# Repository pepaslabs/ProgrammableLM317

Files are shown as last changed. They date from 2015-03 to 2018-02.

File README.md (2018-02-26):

# ProgrammableLM317

A TTL-serial programmable LM317 voltage voltage supply circuit board design.

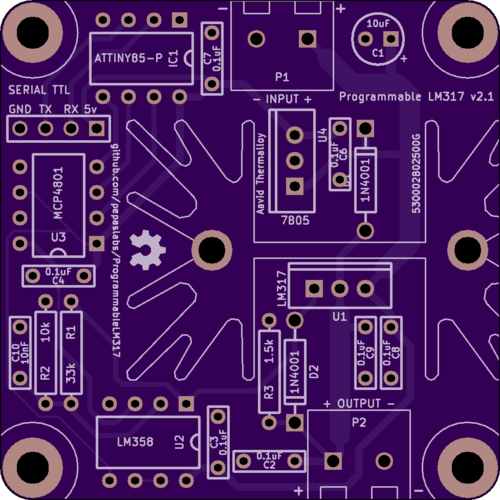
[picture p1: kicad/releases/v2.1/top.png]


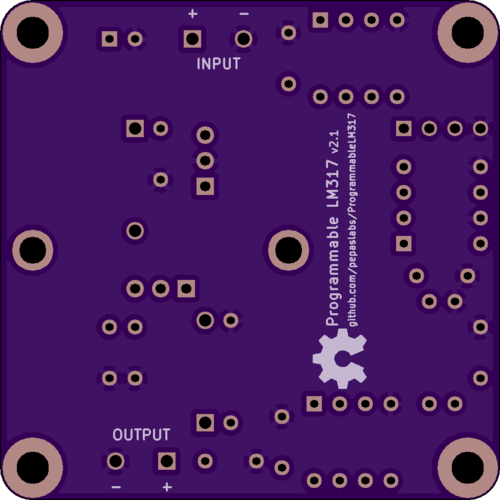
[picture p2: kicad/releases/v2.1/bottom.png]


Schematic: [pdf](kicad/releases/v2.1/ProgrammableLM317.pdf).

Gerbers: [zip](kicad/releases/v2.1/gerbers.zip)

OSHPark: [link](https://oshpark.com/shared_projects/kM7WPtAO)

## License

This board design is [Open-Source Hardware](http://www.oshwa.org/definition/).  It is licensed under the [MIT License](http://opensource.org/licenses/MIT).  It was designed by Jason Pepas.

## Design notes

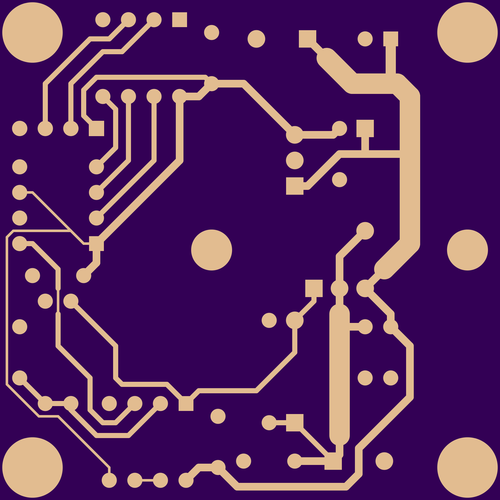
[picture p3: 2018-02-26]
kicad/releases/v2.1/top-copper.png

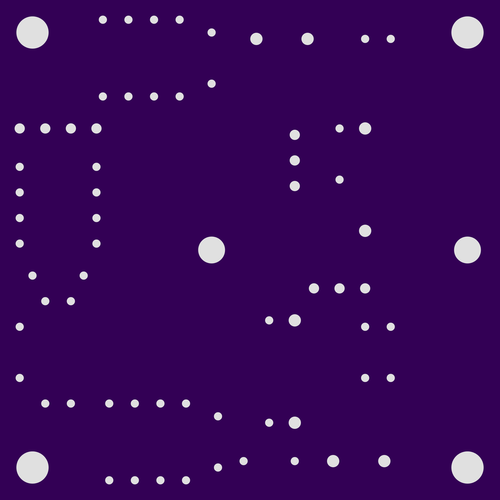
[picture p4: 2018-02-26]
kicad/releases/v2.1/drills.png

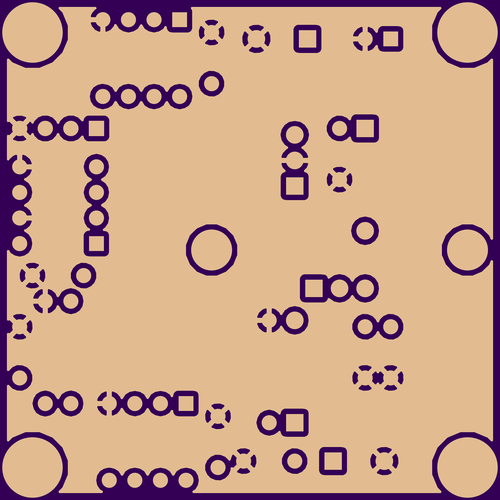
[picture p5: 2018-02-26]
kicad/releases/v2.1/bottom-copper.png

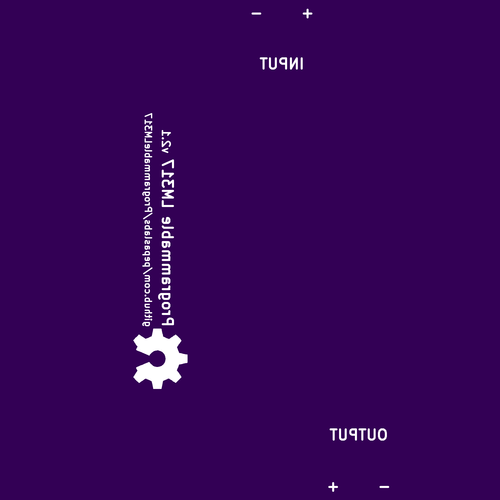
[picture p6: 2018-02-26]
kicad/releases/v2.1/bottom-silk.png

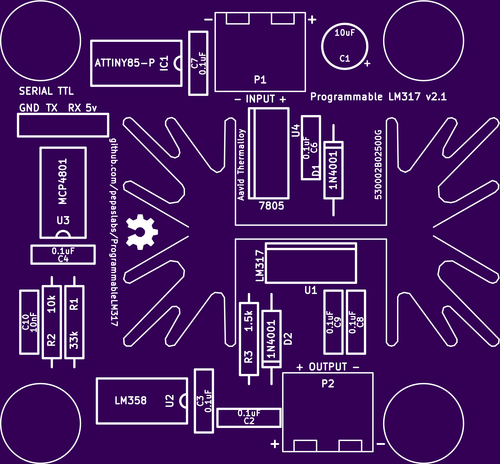
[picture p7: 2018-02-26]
kicad/releases/v2.1/top-silk.png

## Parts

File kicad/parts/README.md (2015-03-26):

KiCADParts
==========

A collection of KiCAD schematic symbols and component footprints which I have created / tweaked / used.

## Design Constraints / Preferred Values / Conventions

* Label size X / size Y / thickness ratio: 1 / 1 / 0.2
 * Preferred component value label size X / size Y / thickness: 0.03" / 0.03" / 0.006"
 * Minimum component value label size X / size Y / thickness: 0.025" / 0.025" / 0.005"
* Outline thickness: 0.01"

## Pads

* Ratios:
 * **_A_**: Size X: 1, Size Y: 1, Offset Y: 0
 * **_B_**: Size X: 1, Size Y: 1.5, Offset Y: 0.25
 * **_C_**: Size X: 1, Size Y: 2, Offset Y: 0

### 0.060" nominal pads

0.059 pads

Pads sized just under 0.060" (allows routing a 0.020" trace without violating DRC).

 * **_059A_**: Size X: 0.059", Size Y: 0.059", Offset Y: 0
 * **_059B_**: Size X: 0.059", Size Y: 0.0885", Offset Y: 0.01475"
 * **_059C_**: Size X: 0.059", Size Y: 0.118", Offset Y: 0

Drill size is 0.032" (the KiCAD default), which is used for:
 * 1/4W resistors
 * small signal diodes
 * ceramic and small electrolytic capacitors
 * DIP leads
 * TO-92 leads

### 0.070" nominal pads

0.069 pads

Pads sized just under 0.070" (allows routing a 0.010" trace without violating DRC).

 * **_069A_**: Size X: 0.069", Size Y: 0.069", Offset Y: 0
 * **_069B_**: Size X: 0.069", Size Y: 0.1035", Offset Y: 0.01725"
 * **_069C_**: Size X: 0.069", Size Y: 0.138", Offset Y: 0

Drill size is 0.040", which is used for:
 * 1/2W resistors
 * TO-220 leads

### 0.080" nominal pads

0.079 pads

Pads sized just under 0.080" (does not allow routing traces).

 * **_079A_**: Size X: 0.079", Size Y: 0.079", Offset Y: 0
 * **_079B_**: Size X: 0.079", Size Y: 0.1185", Offset Y: 0.01975"
 * **_079C_**: Size X: 0.079", Size Y: 0.158", Offset Y: 0

Drill size is 0.056", which is used for:
 * TO-218 leads
 * TO-247 leads

## Footprints

resistors_PL.mod

DIP_PL.mod

transistors_PL.mod

TO-220_PL.mod

## License

Parts which I have created are released under the [MIT License](http://opensource.org/licenses/MIT).  Parts which I have modified are subject to their original license.

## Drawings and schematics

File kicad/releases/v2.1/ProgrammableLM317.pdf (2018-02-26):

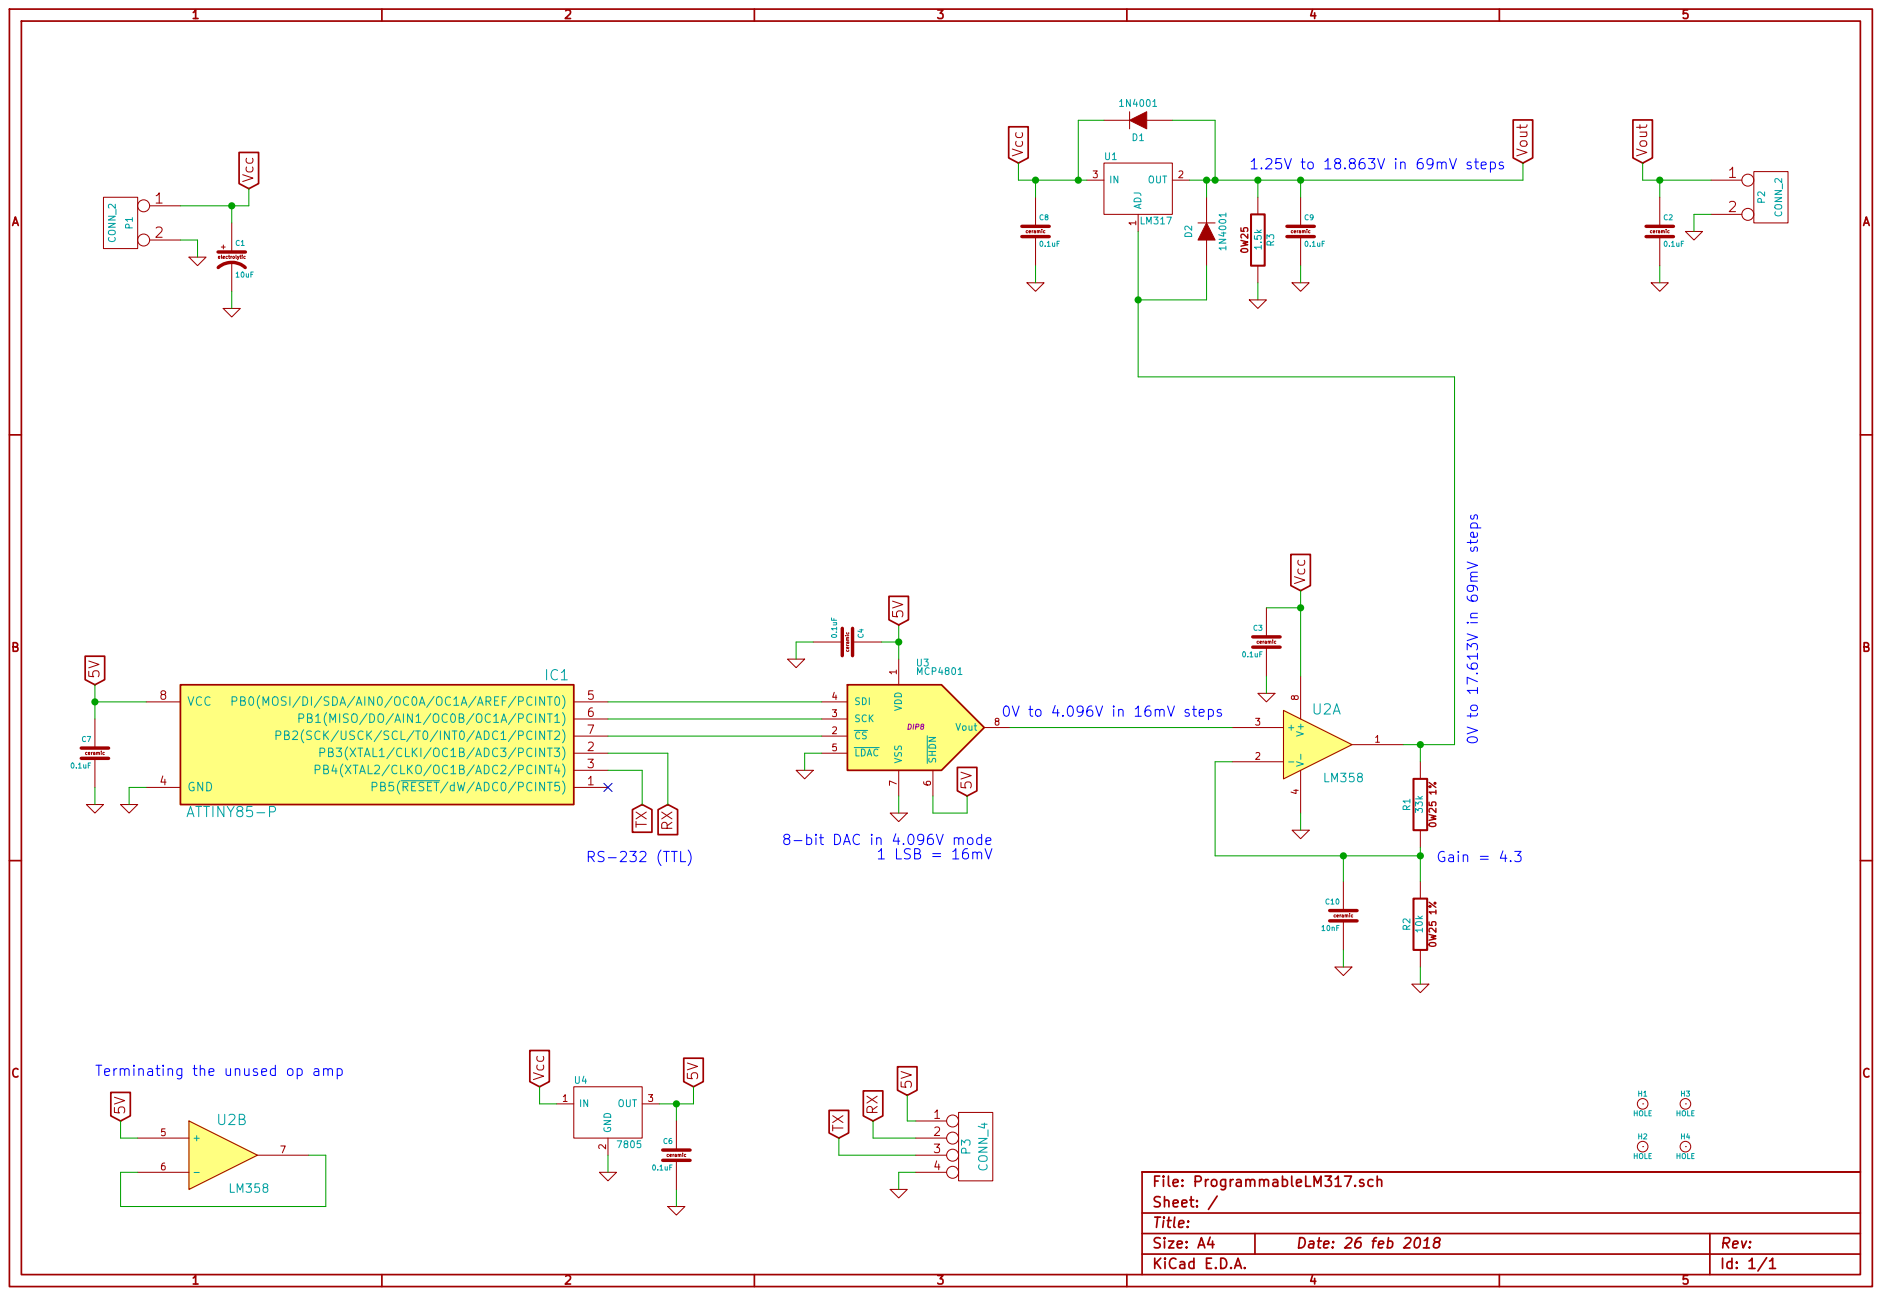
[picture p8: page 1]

8-bit DAC in 4.096V mode

Terminating the unused op amp

Id: 1/1 Title: File: ProgrammableLM317.sch

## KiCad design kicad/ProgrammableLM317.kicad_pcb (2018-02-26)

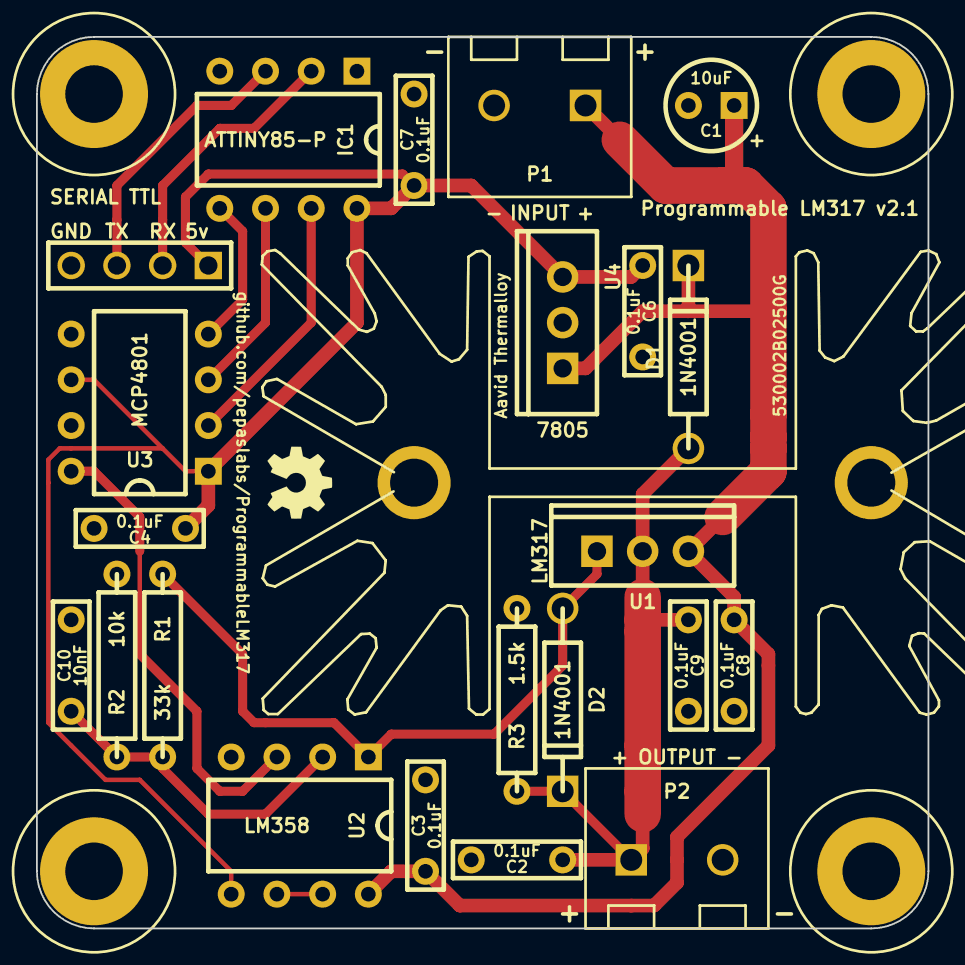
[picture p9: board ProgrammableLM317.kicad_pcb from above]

Board: 2 copper layers, 49.5 x 49.5 mm, 27 parts (0 on the bottom side), 13 nets.

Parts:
C1: 10uF; ELCAP_10_20_V_059A
C2, C3, C4, C6, C7, C8, C9: 0.1uF; CERCAP_2_059A
C10: 10nF; CERCAP_2_059A
D1, D2: 1N4001; DIODE_1A_069A_04_PL
H1, H2, H3, H4: HOLE; hole_M3
H***: 530002B02500G
IC1: ATTINY85-P; DIP8_059A
P1, P2: CONN_2; TERMINAL_BLOCK_2_5mm
P3: CONN_4; PIN_ARRAY_4x1
R1: 33k; R_AXIAL_0W25_059A
R2: 10k; R_AXIAL_0W25_059A
R3: 1.5k; R_AXIAL_0W25_059A
U1: LM317; TO-220_V_069A
U2: LM358; DIP8_059A
U3: MCP4801; DIP8_059A
U4: 7805; TO-220_V_069A

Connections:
5V: C4.1, C6.1, C7.1, IC1.8, P3.1, U2.5, U3.1, U3.6, U4.3
GND: C1.2, C2.2, C3.2, C4.2, C6.2, C7.2, C8.2, C9.2, C10.2, IC1.4, P1.2, P2.2, P3.4, R2.2, R3.2, U2.4, U3.5, U3.7, U4.2
unnamed: IC1.5, U3.4
unnamed: IC1.6, U3.3
unnamed: IC1.7, U3.2
unnamed: U2.6, U2.7
unnamed: D2.1, R1.1, U1.1, U2.1
unnamed: C10.1, R1.2, R2.1, U2.2
unnamed: U2.3, U3.8
RX: IC1.2, P3.2
TX: IC1.3, P3.3
Vcc: C1.1, C3.1, C8.1, D1.2, P1.1, U1.3, U2.8, U4.1
Vout: C2.1, C9.1, D1.1, D2.2, P2.1, R3.1, U1.2

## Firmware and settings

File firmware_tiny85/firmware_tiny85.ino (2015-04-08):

/*
  firmware_tiny85.ino: Arduino sketch for the Programmable LM317 project.  See https://github.com/pepaslabs/ProgrammableLM317
  Copyright Jason Pepas (Pepas Labs, LLC)
  Released under the terms of the MIT License.  See http://opensource.org/licenses/MIT
*/

#define __STDC_LIMIT_MACROS
#include <stdint.h>

#include "features.h"

#include <SoftwareSerial.h>

#include "buffer.h"
#include "pins.h"
#include "SPI_util.h"
#include "DAC_util.h"
#include "MCP4821.h"

#include "command.h"


// ATtiny85 pinout:
//
//                            +--\/--+
//                       D5  -|1    8|-  Vcc   (to 5V)
//      TTL serial RX    D3  -|2    7|-  D2    SPI CS (to DAC CS, pin 2)
//      TTL serial TX    D4  -|3    6|-  D1    SPI SCK (to DAC SCK, pin 3)
//                      GND  -|4    5|-  D0    SPI MOSI (to DAC SDI, pin 4)
//                            +------+

// MCP4821 pinout:
//
//                            +--\/--+
//             (to 5V)  Vcc  -|1    8|-  Vout
//   (to tiny85 pin 5)  ~CS  -|2    7|-  GND
//   (to tiny85 pin 7)  SCK  -|3    6|-  ~SHDN  (to 5V)
//   (to tiny85 pin 6)  SDI  -|4    5|-  ~LDAC  (to GND)
//                            +------+


// --- DAC / SPI:


DAC_config_t dac_config = MCP4821_config();

DAC_data_t dac_data = { .config = &dac_config, .gain = false, .code = 0x0 };


SPI_bus_t spi_bus = { .MOSI_pin = ATTINY85_PIN_5,
                      .MISO_pin = PIN_NOT_CONNECTED,
                      .SCK_pin = ATTINY85_PIN_6
                    };
                    
SPI_device_t spi_dac = { .bus = &spi_bus,
                         .CS_pin = ATTINY85_PIN_7,
                         .bit_order = MSBFIRST
                       };


// --- Serial interface:


#define RX_pin ATTINY85_PIN_2
#define TX_pin ATTINY85_PIN_3

SoftwareSerial serial(RX_pin, TX_pin);


/*

Serial terminal interface:

Set the output voltage to 5 volts:

    v5.000;

Set the DAC output code to 255, no gain:

    c255;

Set the DAC output code to 4095 (12-bit DAC), with 2x gain:

    C4095;

Increase the DAC output by one LSB:

    +;

Decrease the DAC output by one LSB:

    -;

Calibrate the (op amp) gain:

    g4.3;

Calibrate the LM317 VREF:

    r1.25;

Dump the current state:

    ?;

*/


// --- buffer


#define MIN_EXPECTED_BUFF_LEN 2 // "+;"
#define MAX_EXPECTED_BUFF_LEN 9 // "v12.3456;"
#define BUFF_LEN (MAX_EXPECTED_BUFF_LEN + sizeof('\0'))

char buffer_bytes[BUFF_LEN];
char_buffer_t buffer = { .len = BUFF_LEN, .bytes = buffer_bytes };


// --- globals


float LM317_vref = 1.25;
float op_amp_gain = 4.3;


// ---


void setup()
{
  #ifdef HAS_EEPROM_BACKED_CALIBRATION_VALUES
  {
    bootstrap_EEPROM();
  }
  #endif
  
  serial.begin(9600);

  #ifdef HAS_BOOT_MESSAGE
  {
    delay(10);
    serial.print("LM317 OK;");
    serial.flush();
  }
  #endif
  
  // setup soft SPI
  pinMode(spi_bus.MOSI_pin, OUTPUT);
  pinMode(spi_bus.SCK_pin, OUTPUT);
  pinMode(spi_dac.CS_pin, OUTPUT);
  
  digitalWrite(spi_dac.CS_pin, HIGH); // start with the DAC un-selected.

  clear_char_buffer(&buffer);
}


void loop()
{
  command_t command = read_command(&serial, &buffer);
  if (command >= END_OF_COMMANDS_SECTION)
  {
    #ifdef HAS_ERROR_PRINTING
    {
      printError(command);
    }
    #endif
    
    return;
  }

  error_t error;
  
  switch(command)
  {
    
    #ifdef HAS_INCREMENT_COMMAND
    case COMMAND_INCREMENT:
    {
      error = increment_output_voltage(&dac_data, &spi_dac);
      break;
    }
    #endif
  
    #ifdef HAS_DECREMENT_COMMAND
    case COMMAND_DECREMENT:
    {
      error = decrement_output_voltage(&dac_data, &spi_dac);
      break;
    }
    #endif
  
    #ifdef HAS_VOLTS_COMMAND
    case COMMAND_SET_VOLTS:
    {
      error = parse_and_run_voltage_command(&buffer, &dac_data, &spi_dac);
      break;
    }
    #endif
  
    #ifdef HAS_CODE_COMMAND
    case COMMAND_SET_CODE:
    {
      error = parse_and_run_code_command(&buffer, &dac_data, &spi_dac);
      break;
    }
    #endif

    #ifdef HAS_CALIBRATE_OP_AMP_GAIN_COMMAND
    case COMMAND_CALIBRATE_OP_AMP_GAIN:
    {
      error = parse_and_run_calibrate_gain_command(&buffer, &dac_data, &spi_dac);
      break;
    }
    #endif
  
    #ifdef HAS_CALIBRATE_LM317_VREF_COMMAND
    case COMMAND_CALIBRATE_LM317_VREF:
    {
      error = parse_and_run_calibrate_vref_command(&buffer, &dac_data, &spi_dac);
      break;
    }
    #endif
  
    #ifdef HAS_DUMP_COMMAND
    case COMMAND_DUMP:
    {
      error = dump(&dac_data);
      break;
    }
    #endif
    
    default:
    {
      error = ERROR_UNKNOWN_COMMAND;
      break;
    }
  }
  
  if (error != OK_NO_ERROR)
  {
    #ifdef HAS_ERROR_PRINTING
    {
      printError(error);
    }
    #endif
    
    return;
  }
  
  #ifdef HAS_SUCCESS_PRINTING
  {
    printSuccess(command);
  }
  #endif
}


// --- EEPROM


#ifdef HAS_EEPROM_BACKED_CALIBRATION_VALUES

uint8_t EEMEM eeprom_has_been_initialized_token_address;
#define EEPROM_HAS_BEEN_INITIALIZED_CODE 42

float EEMEM LM317_vref_EEPROM_address;

float EEMEM op_amp_gain_EEPROM_address;


bool eeprom_has_been_initialized()
{
  uint8_t has_been_initialized_token = eeprom_read_byte(&eeprom_has_been_initialized_token_address);
  return (has_been_initialized_token == EEPROM_HAS_BEEN_INITIALIZED_CODE);
}


void initialize_eeprom()
{
  eeprom_write_byte(&eeprom_has_been_initialized_token_address, EEPROM_HAS_BEEN_INITIALIZED_CODE);
  eeprom_write_float(&LM317_vref_EEPROM_address, LM317_vref);  
  eeprom_write_float(&op_amp_gain_EEPROM_address, op_amp_gain);
}


void load_values_from_eeprom()
{
  LM317_vref = eeprom_read_float(&LM317_vref_EEPROM_address);
  op_amp_gain = eeprom_read_float(&op_amp_gain_EEPROM_address);
}


void bootstrap_EEPROM()
{
  if (eeprom_has_been_initialized() == false)
  {
    initialize_eeprom();
  }
  else
  {
    load_values_from_eeprom();
  }
}

#endif // HAS_EEPROM_BACKED_CALIBRATION_VALUES


// ---


command_t read_command(SoftwareSerial *serial, char_buffer_t *buffer)
{
  // --- read the first character
  
  while(serial->available() == 0)
  {
    continue;
  }
    
  char ch = serial->read();

  error_t error = read_until_sentinel(serial, buffer, ';');
  if (error != OK_NO_ERROR)
  {
    return error;
  }
  
  switch(ch)
  {
    #ifdef HAS_INCREMENT_COMMAND
    case '+':
    {
      return COMMAND_INCREMENT;
    }
    #endif
    
    #ifdef HAS_DECREMENT_COMMAND
    case '-':
    {
      return COMMAND_DECREMENT;
    }
    #endif
    
    #ifdef HAS_VOLTS_COMMAND
    case 'v':
    {
      return COMMAND_SET_VOLTS;
    }
    #endif
    
    #ifdef HAS_CODE_COMMAND
    case 'c':
    {
      return COMMAND_SET_CODE;
    }
    #endif
    
    #ifdef HAS_CALIBRATE_OP_AMP_GAIN_COMMAND
    case 'g':
    {
      return COMMAND_CALIBRATE_OP_AMP_GAIN;
    }
    #endif
    
    #ifdef HAS_CALIBRATE_LM317_VREF_COMMAND
    case 'r':
    {
      return COMMAND_CALIBRATE_LM317_VREF;
    }
    #endif
    
    default:
    {
      return ERROR_UNKNOWN_COMMAND;
    }
  }
}


error_t read_until_sentinel(SoftwareSerial *serial, char_buffer_t *buffer, char sentinel)
{
  uint8_t num_chars_consumed = 0;
  char *buff_ptr = buffer->bytes;
  
  while(true)
  {
    while(serial->available() == 0)
    {
      continue;
    }
    
    *buff_ptr = serial->read();
    num_chars_consumed++;

    if (*buff_ptr == sentinel)
    {
      *buff_ptr = '\0';
      return OK_NO_ERROR;
    }
    else if (num_chars_consumed == buffer->len - 1)
    {
      *buff_ptr = '\0';
      return ERROR_BUFFER_FILLED_UP_BEFORE_SENTINEL_REACHED;
    }
    else
    {
      buff_ptr++;
      continue;
    }  
  }
}


void send_dac_data(DAC_data_t *dac_data, SPI_device_t *spi_dac)
{
  MCP4821_packet_t packet = dac_data_as_MCP4821_packet(dac_data);
  spi_write_MCP4821_packet(spi_dac, packet);
}


#ifdef HAS_INCREMENT_COMMAND
error_t increment_output_voltage(DAC_data_t *dac_data, SPI_device_t *spi_dac)
{
  if (dac_data_increment_code(dac_data) == false)
  {
    return ERROR_INCREMENT_WOULD_CAUSE_OVERFLOW;
  }

  send_dac_data(dac_data, spi_dac);
  return OK_NO_ERROR;
}
#endif


#ifdef HAS_DECREMENT_COMMAND
error_t decrement_output_voltage(DAC_data_t *dac_data, SPI_device_t *spi_dac)
{
  if (dac_data_decrement_code(dac_data) == false)
  {
    return ERROR_DECREMENT_WOULD_CAUSE_UNDERFLOW;
  }

  send_dac_data(dac_data, spi_dac);
  return OK_NO_ERROR;
}
#endif


#ifdef HAS_VOLTS_COMMAND
error_t parse_and_run_voltage_command(char_buffer_t *buffer, DAC_data_t *dac_data, SPI_device_t *spi_dac)
{
  float output_volts = atof(buffer->bytes);
  
  #ifdef HAS_VOLTS_COMMAND_DEBUGGING
  {
    serial.println();
    serial.print("parsed volts: ");
    serial.println(output_volts, 4);
    serial.flush();
  }
  #endif

  if (output_volts < 0)
  {
    return ERROR_PARSED_VOLTAGE_OUTSIDE_SUPPORTED_RANGE;
  }
  
  float DAC_volts = (output_volts - LM317_vref) / op_amp_gain;
    
  if (dac_data_set_voltage(dac_data, DAC_volts) == false)
  {
    return ERROR_PARSED_VOLTAGE_OUTSIDE_SUPPORTED_RANGE;
  }
  
  MCP4821_packet_t packet = dac_data_as_MCP4821_packet(dac_data);
  spi_write_MCP4821_packet(spi_dac, packet);
  
  return OK_NO_ERROR;
}
#endif


#ifdef HAS_CODE_COMMAND
error_t parse_and_run_code_command(char_buffer_t *buffer, DAC_data_t *dac_data, SPI_device_t *spi_dac)
{
  uint16_t new_code = atoi(buffer->bytes);

  #ifdef HAS_CODE_COMMAND_DEBUGGING
  {
    serial.println();
    serial.print("parsed code: ");
    serial.println(new_code);
    serial.flush();
  }
  #endif

  if (dac_data_set_code(dac_data, new_code) == false)
  {
    return ERROR_PARSED_CODE_OUTSIDE_SUPPORTED_RANGE;
  }
  
  send_dac_data(dac_data, spi_dac);
  return OK_NO_ERROR;
}
#endif


#ifdef HAS_CALIBRATE_OP_AMP_GAIN_COMMAND
error_t parse_and_run_calibrate_gain_command(char_buffer_t *buffer, DAC_data_t *dac_data, SPI_device_t *spi_dac)
{
  float new_gain = atof(buffer->bytes);
  
  #ifdef HAS_CALIBRATE_OP_AMP_GAIN_COMMAND_DEBUGGING
  {
    serial.println();
    serial.print("parsed gain: ");
    serial.println(new_gain, 4);
    serial.flush();
  }
  #endif
  
  if (new_gain < 1.0)
  {
    return ERROR_PARSED_GAIN_OUTSIDE_SUPPORTED_RANGE;
  }
  
  op_amp_gain = new_gain;
  
  #ifdef HAS_EEPROM_BACKED_CALIBRATION_VALUES
  {
    eeprom_write_float(&op_amp_gain_EEPROM_address, op_amp_gain);
  }
  #endif
  
  return OK_NO_ERROR;  
}
#endif


#ifdef HAS_CALIBRATE_LM317_VREF_COMMAND
error_t parse_and_run_calibrate_vref_command(char_buffer_t *buffer, DAC_data_t *dac_data, SPI_device_t *spi_dac)
{
  float new_vref = atof(buffer->bytes);
  
  #ifdef HAS_CALIBRATE_LM317_VREF_COMMAND_DEBUGGING
  {
    serial.println();
    serial.print("parsed vref: ");
    serial.println(new_vref, 4);
    serial.flush();
  }
  #endif
  
  if (new_vref < 0)
  {
    return ERROR_PARSED_VREF_OUTSIDE_SUPPORTED_RANGE;
  }
  
  LM317_vref = new_vref;
  
  #ifdef HAS_EEPROM_BACKED_CALIBRATION_VALUES
  {
    eeprom_write_float(&LM317_vref_EEPROM_address, LM317_vref);  
  }
  #endif
  
  return OK_NO_ERROR;  
}
#endif


#ifdef HAS_ERROR_PRINTING
void printError(error_t error)
{
  serial.print("!e");
  serial.print(error);
  serial.print(";");
  serial.flush();
}
#endif


#ifdef HAS_SUCCESS_PRINTING
void printSuccess(command_t command)
{
  serial.print("ok");
  serial.print(command);
  serial.print(";");
  serial.flush();
}
#endif


#ifdef HAS_DUMP_COMMAND
error_t dump(DAC_data_t *dac_data)
{
  serial.print("DAC code: ");
  serial.println(dac_data->code);
  serial.print("DAC gain: ");
  serial.println(dac_data->gain);
  serial.print("LM317 vref: ");
  serial.println(LM317_vref, 4);
  serial.print("op amp gain: ");
  serial.println(op_amp_gain, 4);
  serial.flush();
  return OK_NO_ERROR;
}
#endif

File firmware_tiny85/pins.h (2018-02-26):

/*
  pins.h
  Copyright Jason Pepas (Pepas Labs, LLC)
  Released under the terms of the MIT License.  See http://opensource.org/licenses/MIT
*/

#ifndef _PINS_H_
#define _PINS_H_

#include <Arduino.h>


// Arduino logical pin numbering:

#define ARDUINO_PIN_D0 0
#define ARDUINO_PIN_D1 1
#define ARDUINO_PIN_D2 2
#define ARDUINO_PIN_D3 3
#define ARDUINO_PIN_D4 4
#define ARDUINO_PIN_D5 5
#define ARDUINO_PIN_D6 6
#define ARDUINO_PIN_D7 7
#define ARDUINO_PIN_D8 8
#define ARDUINO_PIN_D9 9
#define ARDUINO_PIN_D10 10
#define ARDUINO_PIN_D11 11
#define ARDUINO_PIN_D12 12
#define ARDUINO_PIN_D13 13

#define ARDUINO_PIN_A0 A0
#define ARDUINO_PIN_A1 A1
#define ARDUINO_PIN_A2 A2
#define ARDUINO_PIN_A3 A3
#define ARDUINO_PIN_A4 A4
#define ARDUINO_PIN_A5 A5


// ATmega328 (PDIP) pinout:
//
//                            +---\/---+
//     (PCINT14/!RESET) PC6  -|1     28|-  PC5 (ADC5/SCL/PCINT13)
//        (PCINT16/RXD) PD0  -|2     27|-  PC4 (ADC4/SDA/PCINT12)
//        (PCINT17/TXD) PD1  -|3     26|-  PC3 (ADC3/PCINT11)
//       (PCINT18/INT0) PD2  -|4     25|-  PC2 (ADC2/PCINT10)
//  (PCINT19/OC2B/INT1) PD3  -|5     24|-  PC1 (ADC1/PCINT9)
//     (PCINT20/XCK/T0) PD4  -|6     23|-  PC0 (ADC0/PCINT8)
//                      Vcc  -|7     22|-  GND
//                      GND  -|8     21|-  AVREF
// (PCINT6/XTAL1/TOCS1) PB6  -|9     20|-  AVCC
// (PCINT7/XTAL2/TOSC2) PB7  -|10    19|-  PB5 (SCK/PCINT5)
//    (PCINT21/OC0B/T1) PD5  -|11    18|-  PB4 (MISO/PCINT4)
//  (PCINT22/OC0A/AIN0) PD6  -|12    17|-  PB3 (MOSI/OC2A/PCINT3)
//       (PCINT23/AIN1) PD7  -|13    16|-  PB2 (!SS/OC1B/PCINT2)
//   (PCINT0/CLK0/ICP1) PB0  -|14    15|-  PB1 (OC1A/PCINT1)
//                            +--------+

// ATmega328 -> Arduino pin mapping:
//
//                            +---\/---+
//                           -|1     28|-  A5
//                       D0  -|2     27|-  A4
//                       D1  -|3     26|-  A3
//                       D2  -|4     25|-  A2
//                       D3  -|5     24|-  A1
//                       D4  -|6     23|-  A0
//                      Vcc  -|7     22|-  GND
//                      GND  -|8     21|-  
//                           -|9     20|-  
//                           -|10    19|-  D13
//                       D5  -|11    18|-  D12
//                       D6  -|12    17|-  D11
//                       D7  -|13    16|-  D10
//                       D8  -|14    15|-  D9
//                            +--------+

// (for PDIP package:)

#define  ATMEGA328_PIN_2   ARDUINO_PIN_D0
#define  ATMEGA328_PIN_3   ARDUINO_PIN_D1
#define  ATMEGA328_PIN_4   ARDUINO_PIN_D2
#define  ATMEGA328_PIN_5   ARDUINO_PIN_D3
#define  ATMEGA328_PIN_6   ARDUINO_PIN_D4
#define  ATMEGA328_PIN_11  ARDUINO_PIN_D5
#define  ATMEGA328_PIN_12  ARDUINO_PIN_D6
#define  ATMEGA328_PIN_13  ARDUINO_PIN_D7
#define  ATMEGA328_PIN_14  ARDUINO_PIN_D8
#define  ATMEGA328_PIN_15  ARDUINO_PIN_D9
#define  ATMEGA328_PIN_16  ARDUINO_PIN_D10
#define  ATMEGA328_PIN_17  ARDUINO_PIN_D11
#define  ATMEGA328_PIN_18  ARDUINO_PIN_D12
#define  ATMEGA328_PIN_19  ARDUINO_PIN_D13

#define  ATMEGA328_PIN_23  ARDUINO_PIN_A0
#define  ATMEGA328_PIN_24  ARDUINO_PIN_A1
#define  ATMEGA328_PIN_25  ARDUINO_PIN_A2
#define  ATMEGA328_PIN_26  ARDUINO_PIN_A3
#define  ATMEGA328_PIN_27  ARDUINO_PIN_A4
#define  ATMEGA328_PIN_28  ARDUINO_PIN_A5


// ATtiny85 (PDIP) pinout:
//
//                                      +--\/--+
//        (PCINT5/!RESET/ADC0/dW) PB5  -|1    8|-  Vcc
// (PCINT3/XTAL1/CLKI/!OC1B/ADC3) PB3  -|2    7|-  PB2 (SCK/USCK/SCL/ADC1/T0/INT0/PCINT2)
//  (PCINT4/XTAL2/CLKO/OC1B/ADC2) PB4  -|3    6|-  PB1 (MISO/DO/AIN1/OC0B/OC1A/PCINT1)
//                                GND  -|4    5|-  PB0 (MOSI/DI/SDA/AIN0/OC0A/!OC1A/AREF/PCINT0)
//                                      +------+

// ATtiny85 -> Arduino pin mapping:
//
//                                      +--\/--+
//                                 D5  -|1    8|-  Vcc
//                                 D3  -|2    7|-  D2
//                                 D4  -|3    6|-  D1
//                                GND  -|4    5|-  D0
//                                      +------+

// (for PDIP / SOIC / TSSOP package:)

#define  ATTINY85_PIN_1  ARDUINO_PIN_D5
#define  ATTINY85_PIN_2  ARDUINO_PIN_D3
#define  ATTINY85_PIN_3  ARDUINO_PIN_D4
#define  ATTINY85_PIN_5  ARDUINO_PIN_D0
#define  ATTINY85_PIN_6  ARDUINO_PIN_D1
#define  ATTINY85_PIN_7  ARDUINO_PIN_D2


#endif

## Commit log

2015-03-26 pulling in v1 board design.
    [ProgrammableLM317-B_Cu.gbl, ProgrammableLM317-B_Mask.gbs, ProgrammableLM317-B_SilkS.gbo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]
2015-03-26 adding protection diodes to for the LM317.
2015-03-26 removing superfluous capacitors
    [ProgrammableLM317.sch]
2015-03-26 adding protection diodes to board layout
    [ProgrammableLM317.kicad_pcb]
2015-03-26 staging the v2 release
    [ProgrammableLM317-B_Cu.gbl, ProgrammableLM317-B_Mask.gbs, ProgrammableLM317-B_SilkS.gbo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]
2015-03-26 forgot to update the fill plane after moving some parts around.
    [ProgrammableLM317-B_Cu.gbl, ProgrammableLM317-B_Mask.gbs, ProgrammableLM317-B_SilkS.gbo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]
2015-03-26 updating board renders
2015-03-28 adding initial attempt at writing an Arduino sketch for this.
2015-03-29 reworked the error / command codes. working on feature toggles to allow smaller binaries (maybe ATtiny45?).
    [command_t.h]
2015-03-31 working on Arduino firmware sketch for the ATtiny85.
2015-04-07 rearranging schematic.
    [ProgrammableLM317.sch]
2015-04-07 adding parsing of dac "code. adding gain and offset to output volts command.
2015-04-07 working on adding op amp gain calibration and LM317 VREF offset calibration.
2015-04-07 working on gain and offset calibration support.
2015-04-08 working on EEPROM-backed digital calibration values
2018-02-26 board shots
